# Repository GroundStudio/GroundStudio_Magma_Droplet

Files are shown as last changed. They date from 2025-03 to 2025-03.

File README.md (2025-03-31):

GroundStudio Magma Droplet
====================================
Magma Droplet (https://ardushop.ro/ro/plci-de-dezvoltare/2424-groundstudio-magma-droplet-6427854034717.html)

Get it from [ardushop.ro](https://ardushop.ro/ro/plci-de-dezvoltare/2424-groundstudio-magma-droplet-6427854034717.html)

Explore all the GroundStudio products at [GroundStudio.ro](https://groundstudio.ro/)

Description
-------------------
APM32F103CBT6 based development board wih high-performance ARM® Cortex®-M3 32-bit RISC core operating at a frequency of up to 96MHz, 128kBytes of Flash memory, 20kBytes SRAM, 21 PWM , 2 SPI, 3 UART, 30 Digital Pins and 10 channel 12 bit ADC Pins.

Contents
-------------------

* [/Documentation](https://github.com/GroundStudio/GroundStudio_Magma_Droplet/tree/main/Documentation) -- Datasheets, Schematic.
* [/Hardware](https://github.com/GroundStudio/GroundStudio_Magma_Droplet/tree/main/Hardware) -- CAD schematic and layout files.

Versions
-------------------
*(Not all tags shown)*

* [REV0.4]

License
-------------------

This is released under the [Attribution-ShareAlike 4.0 International (CC BY-SA 4.0)](https://creativecommons.org/licenses/by-sa/4.0/) license.
**You are welcome to use this for commercial purposes.**

Please consider contributing back to this project or others to help the open-source hardware community continue to thrive and grow!

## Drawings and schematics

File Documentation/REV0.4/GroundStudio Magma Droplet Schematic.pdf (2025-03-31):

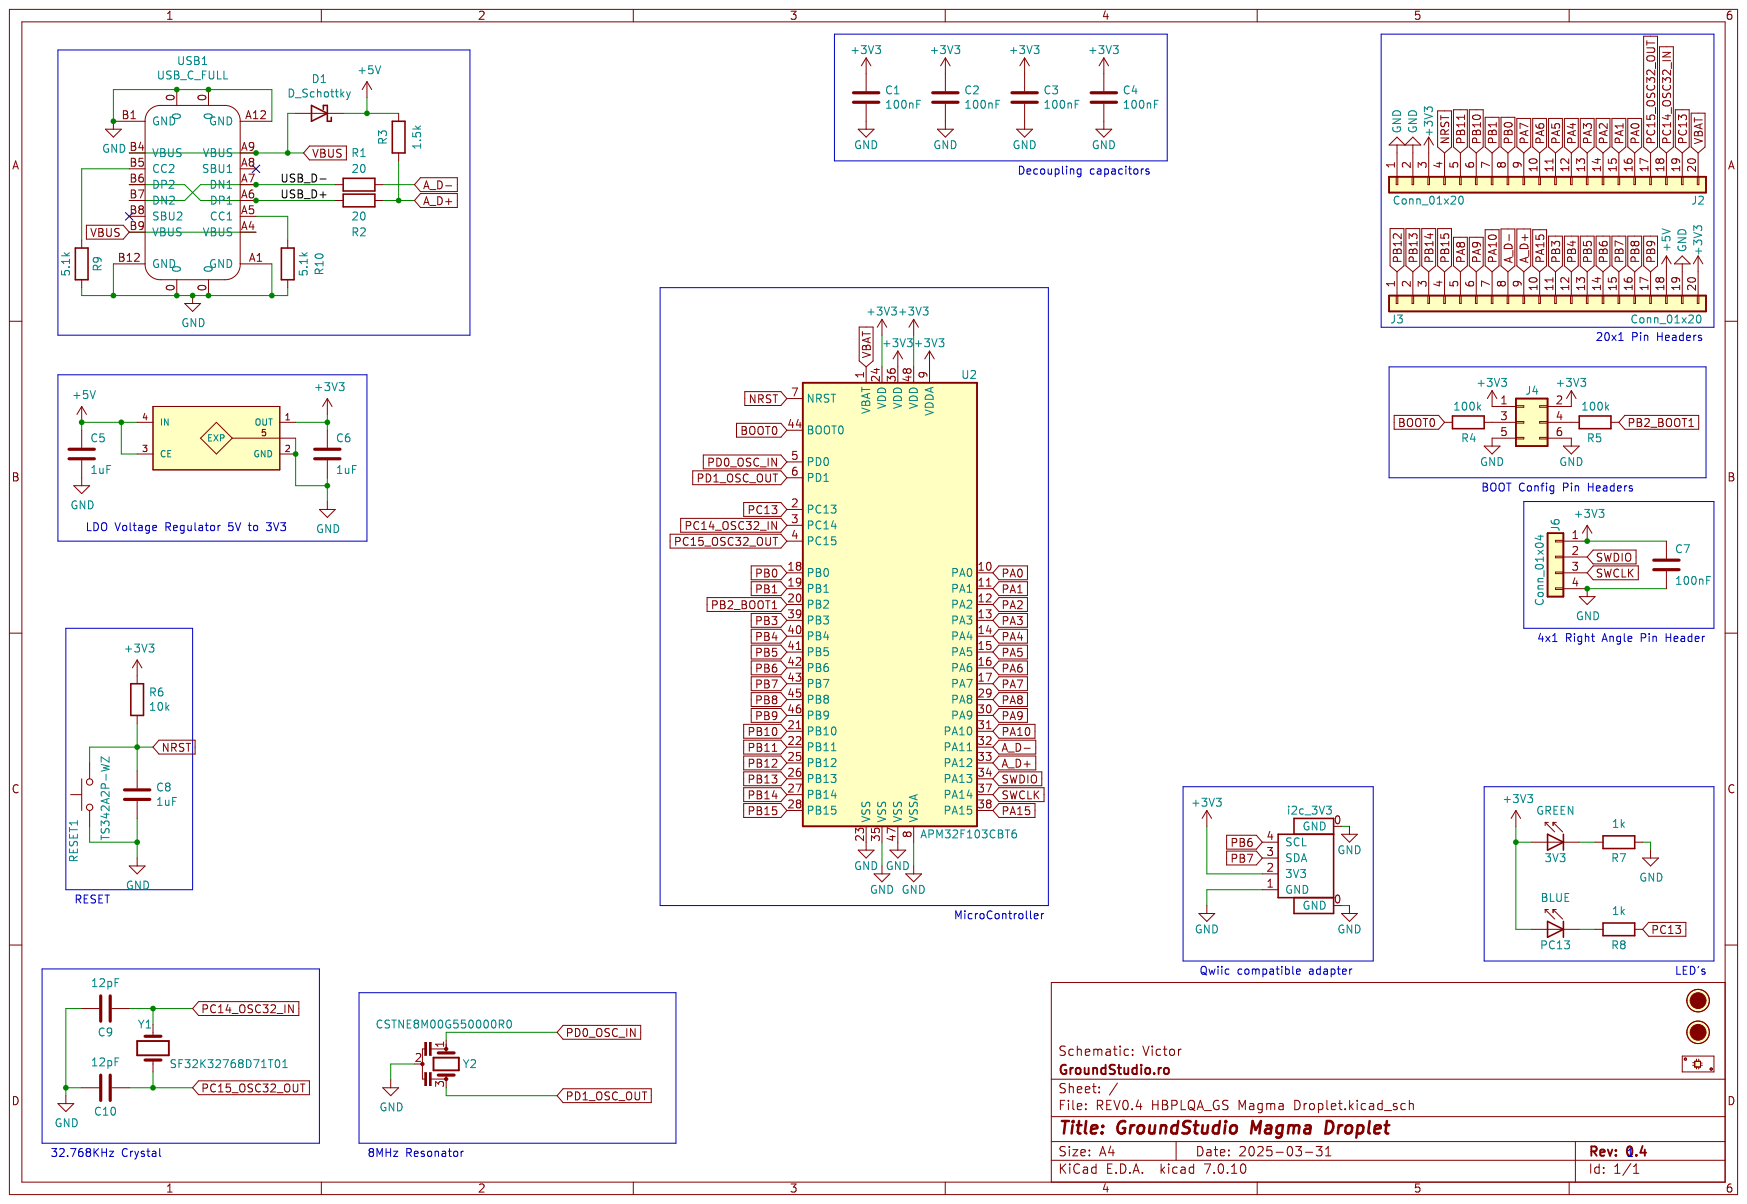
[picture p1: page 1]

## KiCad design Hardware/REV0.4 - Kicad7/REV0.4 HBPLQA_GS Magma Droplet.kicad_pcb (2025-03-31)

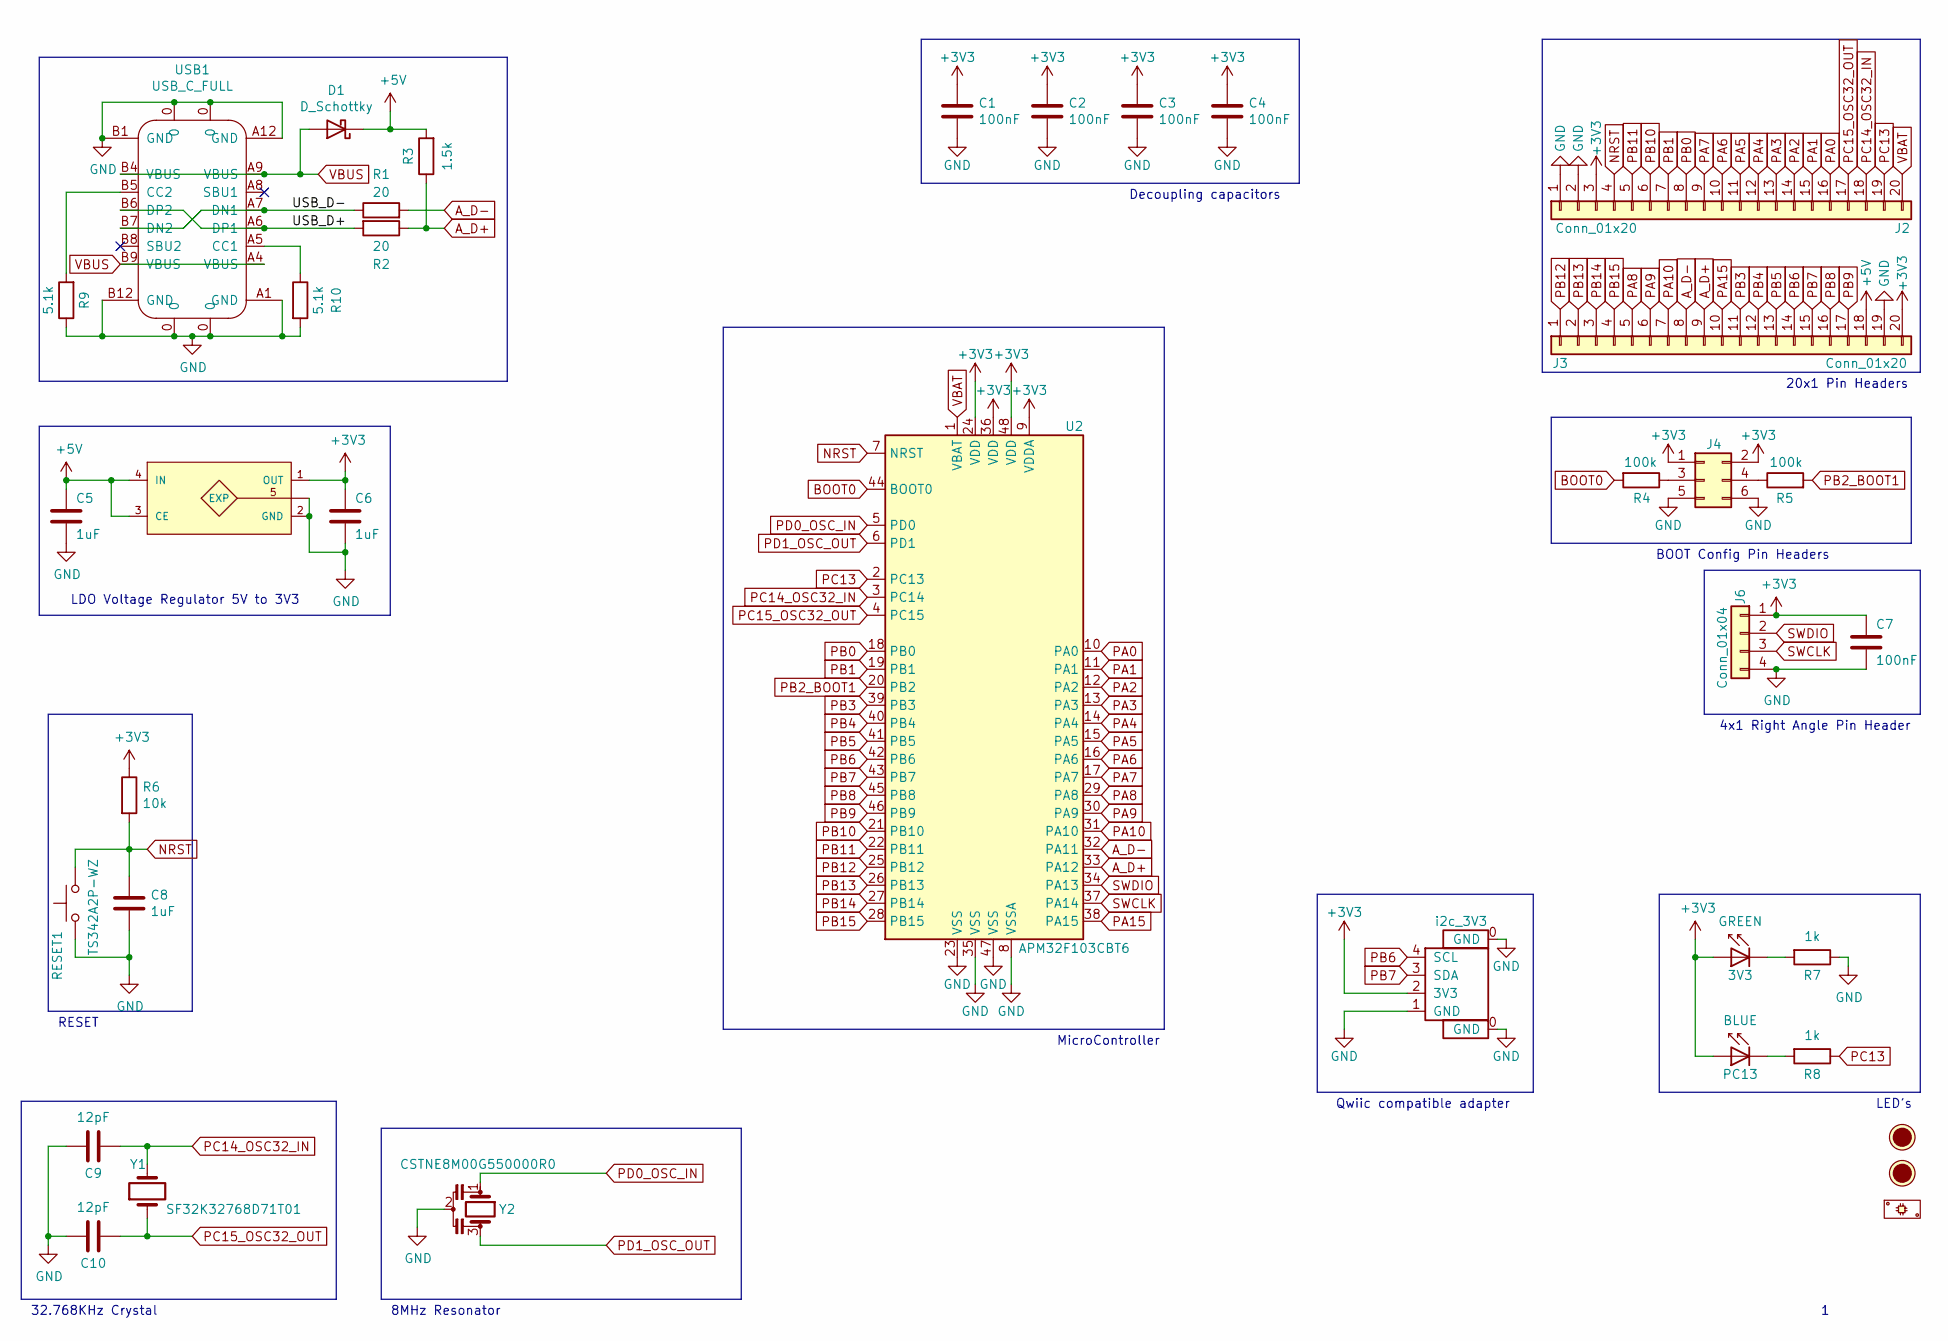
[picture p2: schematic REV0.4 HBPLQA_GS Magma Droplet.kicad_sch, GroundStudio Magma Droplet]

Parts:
3V3: GREEN; LED_0402_1005Metric; MPN TZ-P2-0402GTIA1-0.45T; LCSC C688877
C1, C2, C3, C4, C7: 100nF; C_0402_1005Metric; MPN 0402B104K100CT; LCSC C387941
C5, C6, C8: 1uF; C_0402_1005Metric; MPN FS15B105K100PKG; LCSC C525324
C9, C10: 12pF; C_0402_1005Metric; MPN 0402N120J500CT; LCSC C340641
D1: D_Schottky; SOD-123; MPN B0520LW; LCSC C89640
FID1, FID2: Fiducial; Fiducial_0.75mm_Mask1.5mm
J2, J3: Conn_01x20; PinHeader_1x20_P2.54mm_Vertical_Male; MPN C124374; LCSC C124374
J4: Conn_02x03_Odd_Even; PinHeader_2x03_P2.54mm_Vertical_Male; MPN 210-72-03GB01; LCSC C402781
J6: Conn_01x04; PinHeader_1x04_P2.54mm_Vertical_Male; MPN MTP125-1104S1; LCSC C358686
P1: PCB; MPN HBPLQA_GS_PCB
PC13: BLUE; LED_0402_1005Metric; MPN TZ-P2-0402WYIA1-0.45T; LCSC C779447
R1, R2: 20; R_0402_1005Metric; MPN ERJ2RKF20R0X; LCSC C409897
R3: 1.5k; R_0402_1005Metric; MPN 0402WGF1501TCE; LCSC C25867
R4, R5: 100k; R_0402_1005Metric; MPN 0402WGF1003TCE; LCSC C25741
R6: 10k; R_0402_1005Metric; MPN 0402WGJ0103TCE; LCSC C25531
R7, R8: 1k; R_0402_1005Metric; MPN RC-02W1001FT; LCSC C226166
R9, R10: 5.1k; R_0402_1005Metric; MPN RC-02W5101FT; LCSC C294638
RESET1: TS342A2P-WZ; MPN TS342A2P-WZ; LCSC C557591
U1: ME6211C33U4AG-N; FBP1-1-4; MPN ME6211C33U4AG-N; LCSC C428904
U2: APM32F103CBT6; LQFP-48_7x7mm_P0.5mm; MPN APM32F103CBT6
USB1: USB_C_FULL; USB_C_C167321; MPN 918-418K2023S40001; LCSC C167321
X1: i2c_3V3; SH__1x04_P1.00mm_Horizontal; MPN C145956; LCSC C145956
Y1: SF32K32768D71T01; Crystal_SMD_3215-2Pin_3.2x1.5mm; MPN SF32K32768D71T01; LCSC C271655
Y2: CSTNE8M00G550000R0; Resonator_SMD_muRata_CSTxExxG-3Pin_3.2x1.3mm; MPN CSTNE8M00G55A000R0; LCSC C341523

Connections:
+3V3: 3V3.2 (A), C1.1, C2.1, C3.1, C4.1, C6.1, C7.1, J2.3, J3.20, J4.1, J4.2, J6.1, PC13.2 (A), R6.1, U1.1 (OUT), U2.9 (VDDA), U2.24 (VDD), U2.36 (VDD), U2.48 (VDD), X1.2 (3V3)
+5V: C5.1, D1.1 (K), J3.18, R3.2, U1.3 (CE), U1.4 (IN)
/USB_D+: R2.2, USB1.A6 (DP1), USB1.B6 (DP2)
/USB_D-: R1.1, USB1.A7 (DN1), USB1.B7 (DN2)
A_D+: J3.9, R2.1, R3.1, U2.33 (PA12)
A_D-: J3.8, R1.2, U2.32 (PA11)
BOOT0: R4.2, U2.44 (BOOT0)
GND: C1.2, C2.2, C3.2, C4.2, C5.2, C6.2, C7.2, C8.2, C9.2, C10.2, J2.1, J2.2, J3.19, J4.5, J4.6, J6.4, R7.1, R9.1, R10.2, RESET1.1, U1.2 (GND), U1.5 (EXP), U2.8 (VSSA), U2.23 (VSS), U2.35 (VSS), U2.47 (VSS), USB1.0, USB1.A1 (GND), USB1.A12 (GND), USB1.B1 (GND), USB1.B12 (GND), X1.0 (GND), X1.1 (GND), Y2.2
NRST: C8.1, J2.4, R6.2, RESET1.2, U2.7 (NRST)
unnamed: 3V3.1 (K), R7.2
unnamed: J4.3, R4.1
unnamed: J4.4, R5.1
unnamed: PC13.1 (K), R8.2
unnamed: R9.2, USB1.B5 (CC2)
unnamed: R10.1, USB1.A5 (CC1)
PA0: J2.16, U2.10 (PA0)
PA1: J2.15, U2.11 (PA1)
PA2: J2.14, U2.12 (PA2)
PA3: J2.13, U2.13 (PA3)
PA4: J2.12, U2.14 (PA4)
PA5: J2.11, U2.15 (PA5)
PA6: J2.10, U2.16 (PA6)
PA7: J2.9, U2.17 (PA7)
PA8: J3.5, U2.29 (PA8)
PA9: J3.6, U2.30 (PA9)
PA10: J3.7, U2.31 (PA10)
PA15: J3.10, U2.38 (PA15)
PB0: J2.8, U2.18 (PB0)
PB1: J2.7, U2.19 (PB1)
PB2_BOOT1: R5.2, U2.20 (PB2)
PB3: J3.11, U2.39 (PB3)
PB4: J3.12, U2.40 (PB4)
PB5: J3.13, U2.41 (PB5)
PB6: J3.14, U2.42 (PB6), X1.4 (SCL)
PB7: J3.15, U2.43 (PB7), X1.3 (SDA)
PB8: J3.16, U2.45 (PB8)
PB9: J3.17, U2.46 (PB9)
PB10: J2.6, U2.21 (PB10)
PB11: J2.5, U2.22 (PB11)
PB12: J3.1, U2.25 (PB12)
PB13: J3.2, U2.26 (PB13)
PB14: J3.3, U2.27 (PB14)
PB15: J3.4, U2.28 (PB15)
PC13: J2.19, R8.1, U2.2 (PC13)
PC14_OSC32_IN: C9.1, J2.18, U2.3 (PC14), Y1.2
PC15_OSC32_OUT: C10.1, J2.17, U2.4 (PC15), Y1.1
PD0_OSC_IN: U2.5 (PD0), Y2.1
PD1_OSC_OUT: U2.6 (PD1), Y2.3
SWCLK: J6.3, U2.37 (PA14)
SWDIO: J6.2, U2.34 (PA13)
VBAT: J2.20, U2.1 (VBAT)
VBUS: D1.2 (A), USB1.A4 (VBUS), USB1.A9 (VBUS), USB1.B4 (VBUS), USB1.B9 (VBUS)

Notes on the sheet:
Decoupling capacitors
4x1 Right Angle Pin Header
MicroController
20x1 Pin Headers
8MHz Resonator
32.768KHz Crystal
LDO Voltage Regulator 5V to 3V3
Qwiic compatible adapter
BOOT Config Pin Headers
LED's
RESET

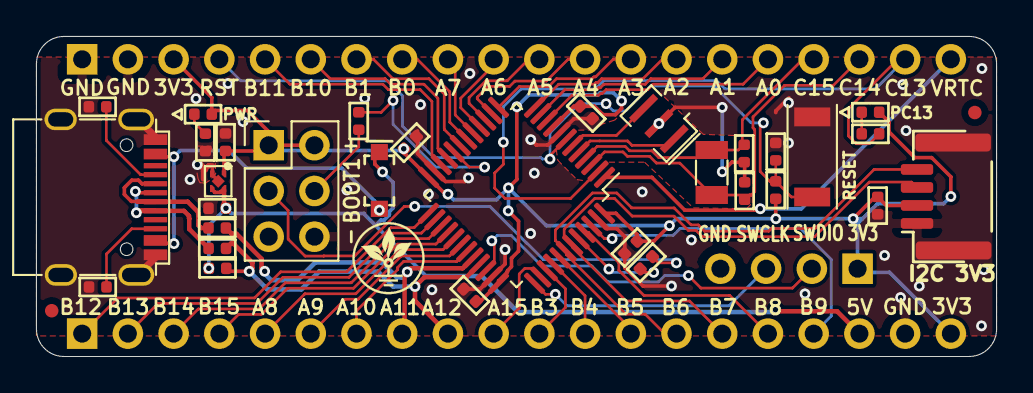
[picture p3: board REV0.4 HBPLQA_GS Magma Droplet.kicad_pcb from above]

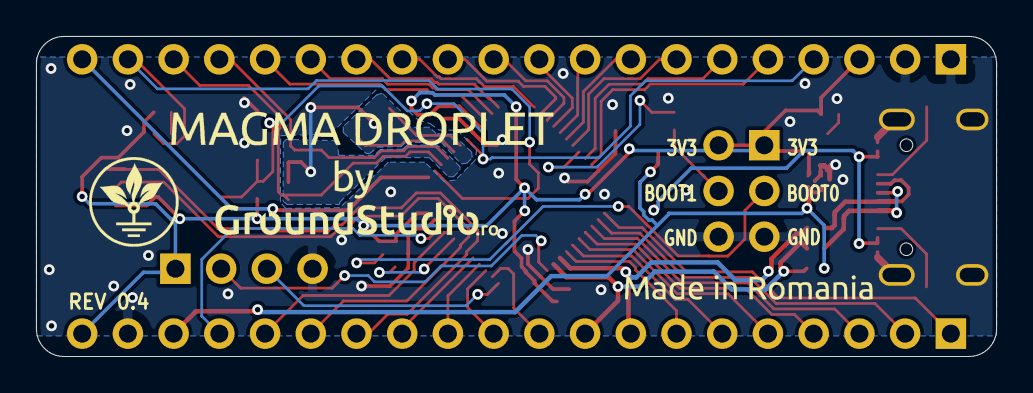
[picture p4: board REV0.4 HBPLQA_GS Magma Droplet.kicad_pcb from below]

Board: 2 copper layers, 53.3 x 17.8 mm, 36 parts (2 on the bottom side), 52 nets.
